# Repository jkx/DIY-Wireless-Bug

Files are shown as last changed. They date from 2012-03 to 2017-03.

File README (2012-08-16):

DIY Wireless Bug
================

bugOne hardware and software git repos. 

You can find more infos here : 
- Introduction => http://dwb.ilhost.fr/doku.php/start
- Hardware => http://dwb.ilhost.fr/doku.php/bugone:hardware

All works here is under CC Attribution-NonCommercial-ShareAlike licence.
Check out this for licence information :
- http://creativecommons.org/licenses/by-nc-sa/3.0/

Brought to you, by MDL29 Electronic Team 
- http://mdl29.net

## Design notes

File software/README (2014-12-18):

Software Guidelines
===================
When you use the bugOne framework to developp apps, please to follow this 
guidelines : 

- LED1 (red one) must be used to represent the power supply. On normal 
  operation it should be ON. If your application need to power consumption,
  you can turn it OFF, but alway turn it ON when the app is running. 

- LED2 (blue one) must be used for radio channel. It should blink on receive
  or transmit. We can imagine two kind of blinking, 1 long for transmition,
  2 short blinks for reception.

- At during boot, both leds should be ON.

- Tabulation, please try to follow the GNU coding style : 4 spaces

- Battery powered bugOne should return the bandgap voltage in the first field

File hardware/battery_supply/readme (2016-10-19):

# Board description

This board is a small battery supply card. It uses a Microchip MCP1640 boost
converter, and is usable with a single 1.5V battery. It is designed to provide a
3.3V (or 5v, depending on the resistor) output on Vcc. 

Please note that this is a very basic board : it does not make use of advanced
features such as Vin to Vout connection and enables. 

# Parts names

U1 : MCP1640
L1 : B82462G4472M (EPCOS), 4.7uH power choke
R1 : 976kOhm, 0805 package
R2 : 562kOhm, 0805 package (for 3.3V)
R2 (alt) : 309kOhm, 0805 package (5V)
C1 : 4.7uF, 1206 package
C2 : 10uF, 1206 package
VIN : 0.7 to 1.7V

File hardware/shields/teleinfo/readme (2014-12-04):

# Board description

This shield is a simple prototype for teleinfo reading. It is based on a simple design, with a single SHF620A optocoupler for demodulation. The LED blinks when data is available on RX.

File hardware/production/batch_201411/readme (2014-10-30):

Production files for November 2014 batch

The aim is to get the following boards : 
	- 70 bugOne_mini
	- 25+ sensor shields
	- 5+ sht21 breakout
	- 35 battery power shields
	- optionnally, 5+ repeater

This has been done in 3 different boards (10x10cm). A .8mm cut line is used, the
cutter can only cut through a whole board, which limits sorting possibilities.

# Boards description

batch1 : 4 bugOne_mini, 2 battery power shields, 2 sht21 breakout
batch2 : 2 bugOne_mini, 2 sensor shields, 2 battery power shields, 1 repeater board
batch3 : same as batch 1

Expected order is 10 batch1, 10 batch2, and 10 batch3. SeeedStudio charges ~22$
10 pieces of 10x10cm printed boards, which amounts to 66$ before taxes and
shipping fees.

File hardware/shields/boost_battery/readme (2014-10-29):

# Board description

This board is a small boost card pin compatible with bugOne Mini. It uses a
Microchip MCP1640 boost converter, and is usable with a single 1.5V battery. It
is designed to provide a 3.3V output on Vcc, and the 1.5V input on Vss if the
jumper is in place (used to check remaining battery with the sensor shield).

# Parts names

U1 : MCP1640
L1 : B82462G4472M (EPCOS), 4.7uH power choke
R1 : 976kOhm, 0805 package
R2 : 562kOhm, 0805 package
C1 : 4.7uF, 1206 package
C2 : 10uF, 1206 package
VIN : 0.7 to 1.7V

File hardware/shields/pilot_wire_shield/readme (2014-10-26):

# Board description

This shield is designed to provide electric heater control through "pilot wire"
interface. It uses 2 MOC to control positive and negative part of the input
sinusoid. It also uses a shift register to store values without need of the AVR.
This shield is designed to go BELOW the bugOne main board. It would otherwise 
hide the antenna and leds.

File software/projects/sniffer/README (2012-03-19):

For your board: use make && make load to flash sniffer.c one your bugOne.

Use python commands to interact with other bugOne cards.

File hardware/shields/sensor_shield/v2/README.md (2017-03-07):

## Board description

This shield is designed to provide different possibilities to create a sensor
shield, for relative humidity, temperature, pressure and lux. All choices do not need to be
soldered. 

## BOM 

The following components can be soldered on the board:
   - TAOS TSL2561 (U1)
   - TE HTU2XD(F) (U2)
   - Maxim DS18B20 (U3): popular 1-Wire temperature sensor Maxim. 
		http://datasheets.maximintegrated.com/en/ds/DS18B20

Other possibilites were:
	- Sensirion SHT31D : cheap (~5$ at Farnell) QFP sensor, using I2C for communication
	https://www.sensirion.com/fileadmin/user_upload/customers/sensirion/Dokumente/Humidity_Sensors/Sensirion_Humidity_Sensors_SHT3x_Datasheet_digital.pdf
	- Bosch BME280 : temperature, humidity and pressure. The package seems more protected than the Sensirion (and we had troubles with the Sensirion which seems to age fast). 
	https://ae-bst.resource.bosch.com/media/_tech/media/datasheets/BST-BME280_DS001-11.pdf
	- Rohm BH1750 : Light sensor (Luxmeter)
	http://rohmfs.rohm.com/en/products/databook/datasheet/ic/sensor/light/bh1750fvi-e.pdf

C1 and C2 stabilizes the power line for their components. Expected value is 100nF. They need to be placed near their components
R1 and R2 are the pull-up resistors for I2C bus. Values can range from 1.8 to 10k. I prefer using 1.8k (strong pull-up), but the higher the resistance, the lower the current consumption. 
R3 is the pull-up for the interrupt line of the TSL2561. Value is 100k (datasheet)
R4 is the pull-up resistor for 1-Wire bus. Expected value is 4.7kOhm.
R5 and R6 are a voltage divider for battery sensing. It divides voltage by 2, allowing a battery up to 6.6V. 
R7 and R8 are only there to provide solder pads. Only one can be soldered at a time. They allow selection of the power line for which the voltage must be measured (Vss or Vcc)

U1, U2 and U3 uses I2C.

Shield pinout : 

CONN1_2 : FOUT, PD5
CONN1-5 : 1-Wire bus, PB1
CONN2_4 : SCL, PC5
CONN2_5 : SDA, PC4
CONN2_6 : battery sense, PC3

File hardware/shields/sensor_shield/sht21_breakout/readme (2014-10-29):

# Board description

Small breakout board for the Sensirion SHT21/SHT25 T/RH sensor. The board is 
compatible with repeater pinout. It also allows a photoresistor on it, for
ambient light sensing.

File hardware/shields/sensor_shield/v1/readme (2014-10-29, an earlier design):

# Board description

This shield is designed to provide different possibilities to create a sensor
shield, for relative humidity and temperature. All choices do not need to be
soldered. A 8P8C (RJ45) modular connector is provided in order to export the sensors
further from the board (to avoid sensor noise). A repeater board is also
provided (in the corresponding subdirectory), in order to connect the sensors
through RJ45 wire.

# BOM

The following components can be soldered on the board:
	- Sensirion SHT21/SHT25 (U1): cheap (~4$) QFP sensor, using I2C for communication
		http://www.sensirion.com/fileadmin/user_upload/customers/sensirion/Dokumente/Humidity/Sensirion_Humidity_SHT21_Datasheet_V4.pdf
		Resolution and precision are interesting, and it is low power (less than 1uA when asleep, 1mA when measuring temp, 330uA when measuring RH). However, it is difficult to solder...
	- HH10D (U2): this is a humidity sensor provided by HopeRF. It is quite expensive but efficient. 
		http://www.hoperf.com/upload/sensor/hh10d.pdf
	- DHT11 (U3): cheap but unprecise RH and temp sensor. It is widely used.
		http://www.exp-tech.de/service/datasheet/DHT11.PDF
	- DS18B20 (U4): popular 1-Wire temperature sensor from Maxim. 
		http://datasheets.maximintegrated.com/en/ds/DS18B20.pdf

2 pull-up resistors can be soldered. 
	R1 is the pull-up resistor for DHT11. Expected value is 5kOhm if the sensor is connected through a wire shorter than 20m. 
	R2 is the pull-up resistor for 1-Wire bus. Expected value is 4.7kOhm.
	R3 and R4 are the pull-up resistors for I2C bus. Values can range from 1.8 to 10k. I prefer using 1.8k (strong pull-up), but the higher the resistance, the lower the current consumption.

# Pinout

RJ45 pinout:

P1: 1-Wire bus, PB1
P2: Vcc
P3: SDA, PC4
P4: SCL, PC5
P5: FOUT pin if HH10D connected (unusable if HH10D on the shield), PD5
P6: DATA1 pin if DHT11 connected (unusable if DHT11 on the shield), PD3
P7: PC2 (ADC pin, usable for light sensor for example)
P8: GND

Shield pinout : 

CONN1_2 : FOUT, PD5
CONN1-5 : 1-Wire bus, PB1
CONN2_3 : DHT11 DATA1, PD3
CONN2_4 : SCL, PC5
CONN2_5 : SDA, PC4
CONN2_6 : battery sense, PC3
CONN2_7 : external connector, PC2

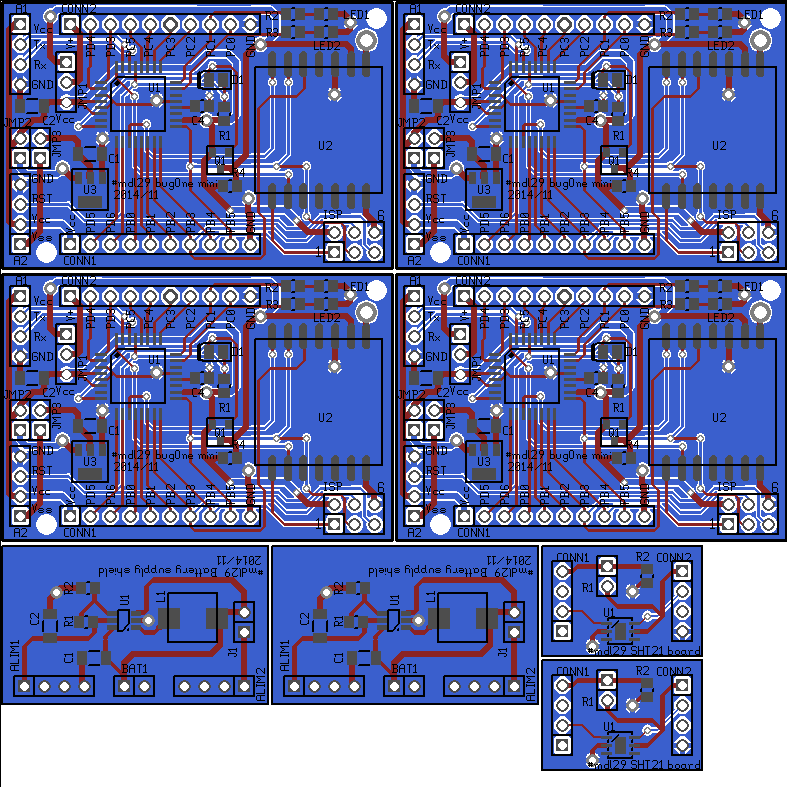
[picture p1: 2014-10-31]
hardware/production/batch_201411/batch1.png

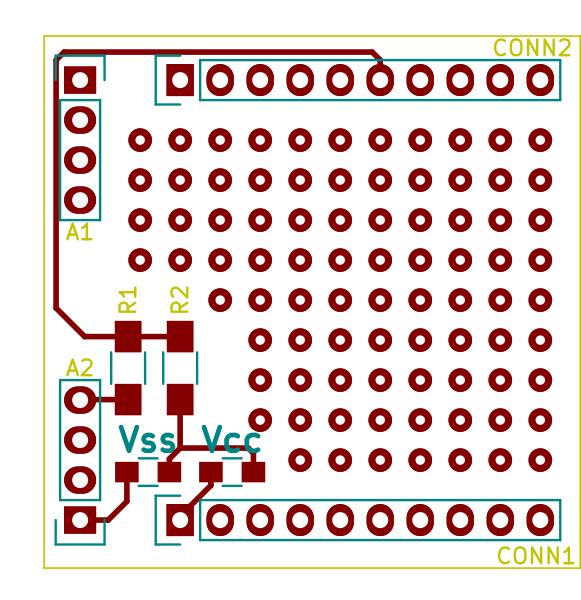
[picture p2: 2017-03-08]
hardware/shields/proto_shield/proto_shield.png

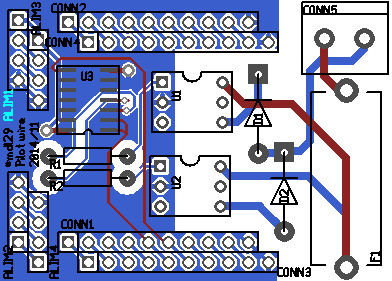
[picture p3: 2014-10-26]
hardware/shields/pilot_wire_shield/pilot_wire.png

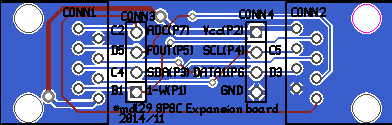
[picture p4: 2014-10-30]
hardware/shields/sensor_shield/repeater/repeater.png

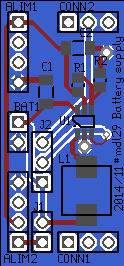
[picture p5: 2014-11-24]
hardware/shields/boost_battery/boost_battery.png

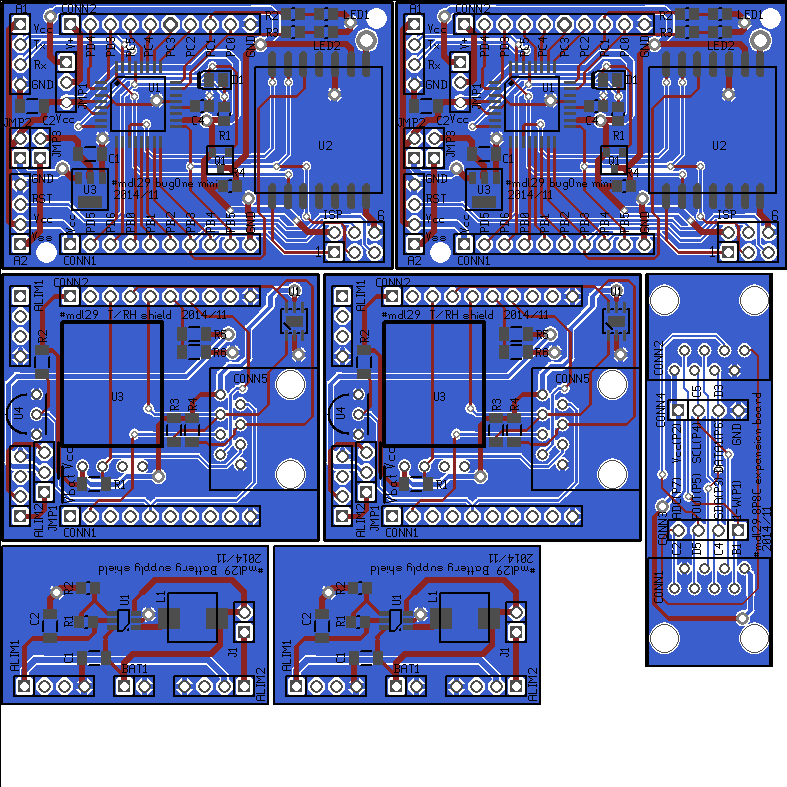
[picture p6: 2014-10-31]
hardware/production/batch_201411/batch2.png

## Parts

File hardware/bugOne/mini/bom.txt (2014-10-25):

Connectors : 
CONN1	: 10 pins female header 
CONN2	: 10 pins female header
ALIM1	: 4 pins female header (can be soldered below to add a bigger power shield)
ALIM2	: 4 pins female header (can be soldered below to add a bigger power shield)
ISP	: 2 rows 3-pins male header

Components : 
U1 	: ATmegaX8 with TQFP-32 package (ATmega168, ATmega328, ATmega8,...)
U2 	: RFM12B from hopeRF (or pin compatible, such as RFM69HW)
U3 	: LDO regulator, Microchip MCP1700 or Torex XC6206, adapts C1 and C2 according to choice. SOT-89 package
Q1		: P-MOSFET, SOT-23 package. Pin example is BSS315P from Infineon (draws 1uA), low cost
R0		: 0 ohm, soldered to replace U3 if no LDO required
R1		: 10k, 0805 package
R2		: 1k, 0805 package
R3		: 1k, 0805 package
R4		: 0 ohm, soldered to replace Q1 if no MOSFET required
C1		: 1206 package, 1u ceramic for XC6206, 
C2		: 1206 package, 1u ceramic for XC6206,
C4		: 100nF, 0805 package
D1		: SOD-323 package, "usual" blocking diod
LED1	: red led
LED2	: blue led

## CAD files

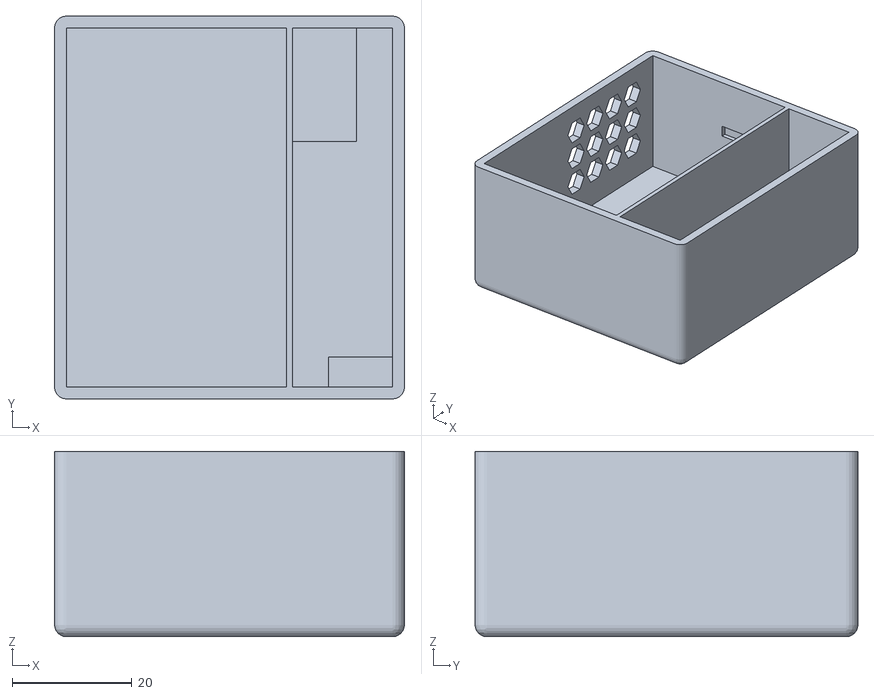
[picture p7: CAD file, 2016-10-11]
hardware/case/bugone_case_vented.stl
58.5 x 64.0 x 31.0

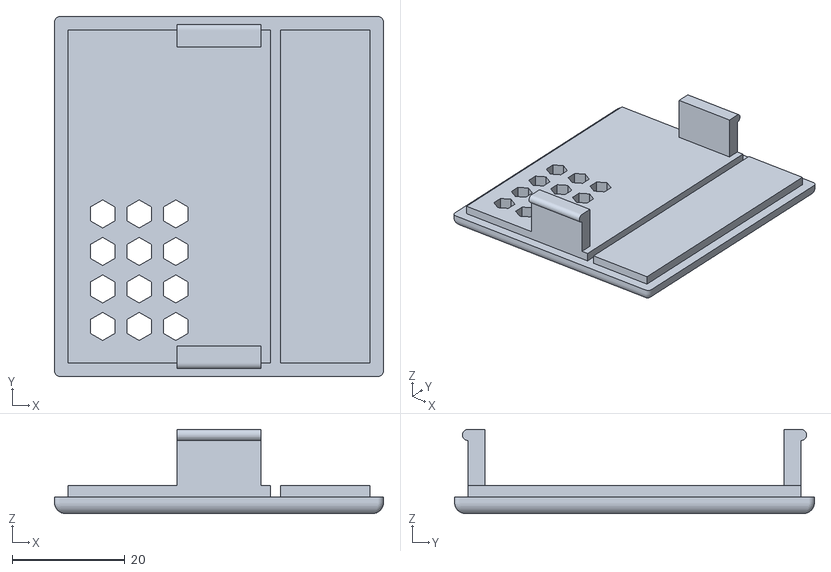
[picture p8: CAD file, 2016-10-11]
hardware/case/bugone_lid_vented.stl
58.5 x 64.0 x 15.0

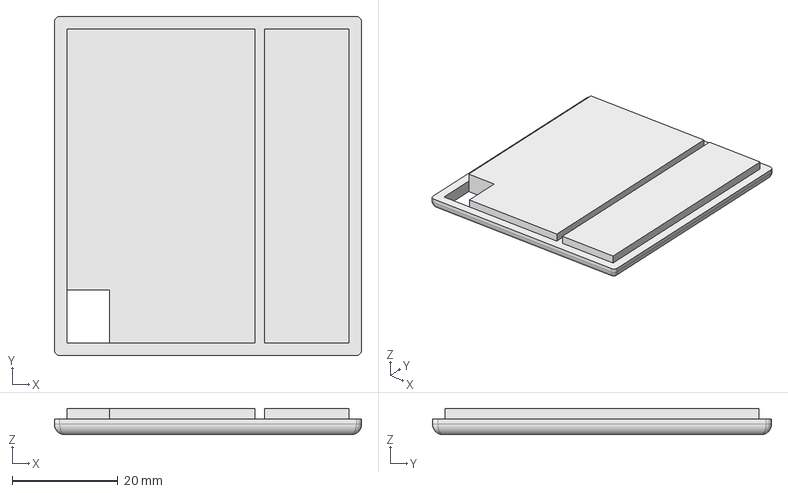
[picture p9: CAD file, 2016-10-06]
hardware/case/bugone_14500_vert_lid.fcstd
58.0 x 64.0 x 5.00 mm

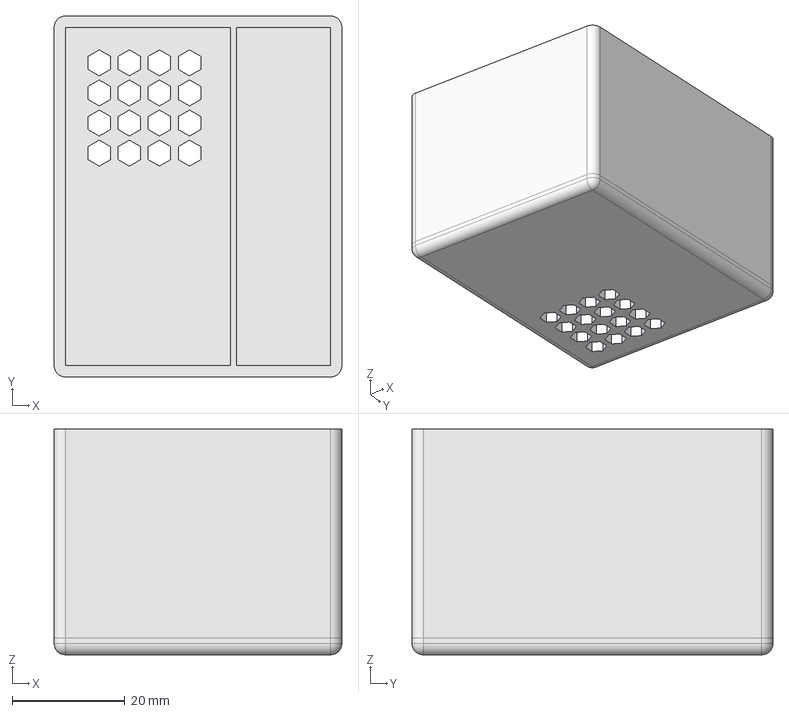
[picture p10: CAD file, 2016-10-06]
hardware/case/bugone_14500_vert_case.fcstd
51.0 x 64.0 x 40.0 mm

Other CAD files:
hardware/case/bugone_14500_lid.fcstd
hardware/case/bugone_14500_case.fcstd

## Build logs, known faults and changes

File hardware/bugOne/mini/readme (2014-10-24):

# Board description

This is a miniaturized version of bugOne board. Power connectors have been
rotated in order to reduce the board length below 50 mm. Shields stay compatible
in size. 

# Noticeable changes

	* A PMOS has been introduced, to provide a shutdown feature on selected
	  devices. RF transmitter can now be completely powered off, by setting pin
	  PB7 as input (a pull up is used), and powerd on by setting it to 0. This
	  controlled power line is accessible as V+ on CONN2.
	* Power connectors have been modified
	* A new LDO regulator is used, either MCP1700 or XC6206 (preferred choice).
	  They aure pin compatible. 
	* Grounded mounting holes are provided. One of them is located near the
	  antenna output, providing an easy way to ground an external antenna.
	* R0 is not used as a fuse anymore, but as a bypass in case no regulator is
	  soldered. The same mechanism is provided by the shield, in order to keep
     the same pinout as before on the shield connectors.
	* ISP connector is now usable even with a shield connected (same line as the
	  antenna)

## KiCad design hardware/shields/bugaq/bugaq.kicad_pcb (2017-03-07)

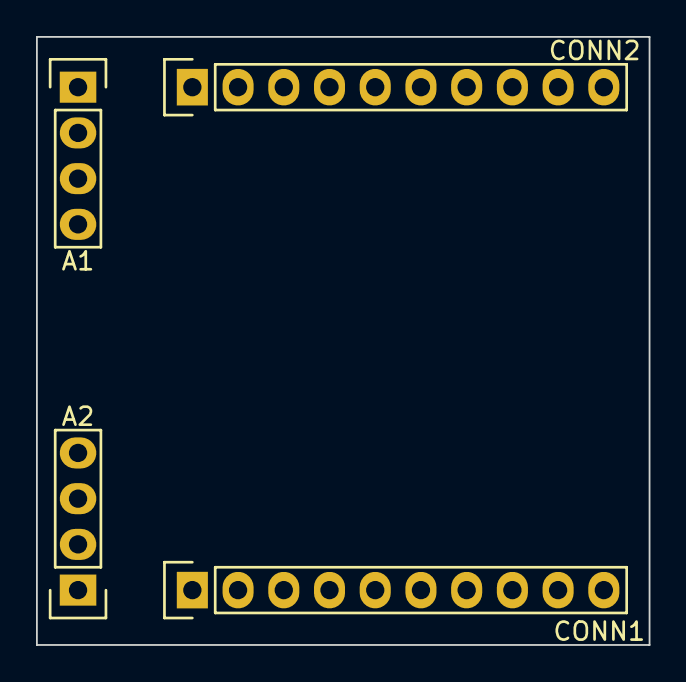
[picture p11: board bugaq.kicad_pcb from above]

Board: 2 copper layers, 34.0 x 33.8 mm, 4 parts (0 on the bottom side), 2 nets, no tracks yet.

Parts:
A1, A2: CONN_01X04; Pin_Header_Straight_1x04
CONN1, CONN2: CONN_01X10; Pin_Header_Straight_1x10

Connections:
GND: A1.4, A2.4, CONN1.10, CONN2.10
VCC: A1.1, A2.2, CONN1.1

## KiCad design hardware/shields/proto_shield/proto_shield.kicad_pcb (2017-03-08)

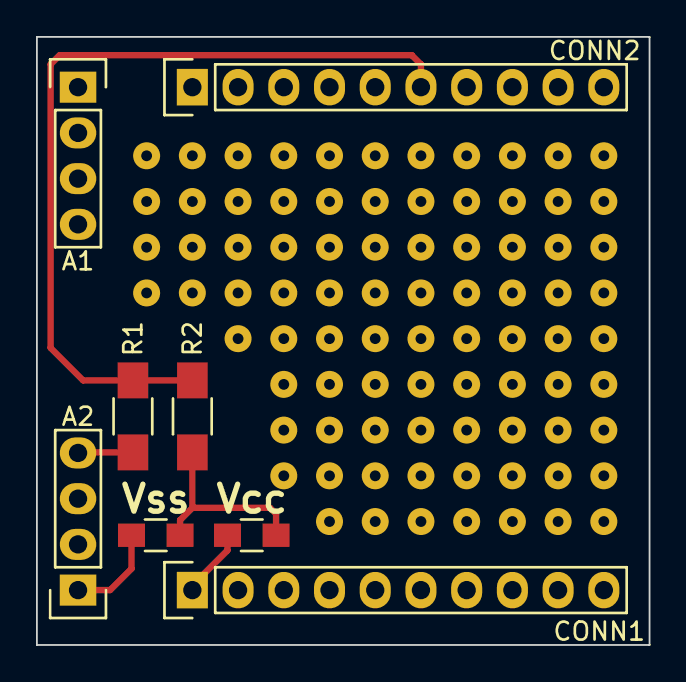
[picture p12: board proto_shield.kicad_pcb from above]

Board: 2 copper layers, 34.0 x 33.8 mm, 8 parts (0 on the bottom side), 5 nets.

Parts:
A1, A2: CONN_01X04; Pin_Header_Straight_1x04
CONN1, CONN2: CONN_01X10; Pin_Header_Straight_1x10
R1, R2: 470k; R_1206_HandSoldering
R7, R8: 0; R_0805_HandSoldering

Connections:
GND: A1.4, A2.4, CONN1.10, CONN2.10, R1.2
unnamed: R2.1, R7.2, R8.2
PC3: CONN2.6, R1.1, R2.2
VCC: A1.1, A2.2, CONN1.1, R7.1
VSS: A2.1, R8.1

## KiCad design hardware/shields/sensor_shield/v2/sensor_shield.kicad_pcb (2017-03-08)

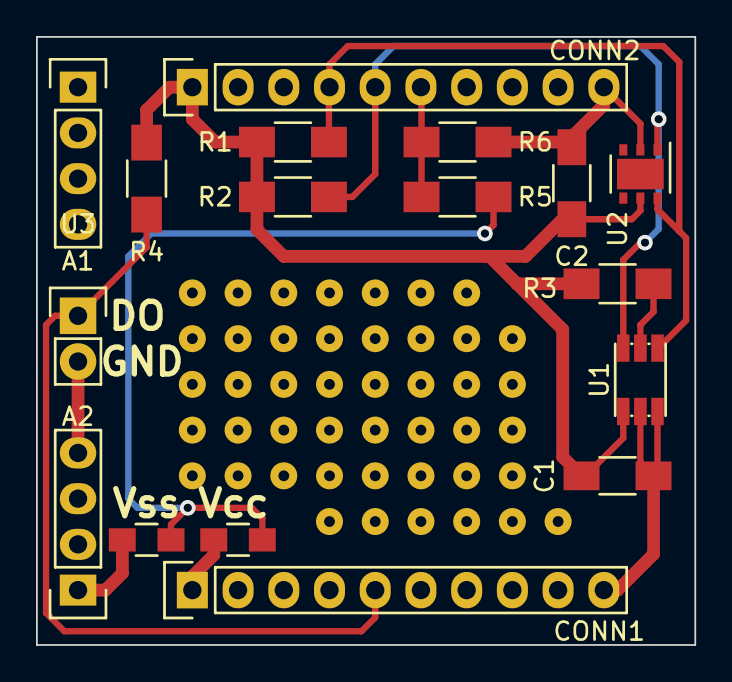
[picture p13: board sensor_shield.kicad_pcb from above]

Board: 2 copper layers, 36.6 x 33.8 mm, 17 parts (0 on the bottom side), 10 nets.

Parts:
A1, A2: CONN_01X04; Pin_Header_Straight_1x04
C1, C2: 100n; C_1206_HandSoldering
CONN1, CONN2: CONN_01X10; Pin_Header_Straight_1x10
R1, R2: 1.8k; R_1206_HandSoldering
R3: 100k; R_1206_HandSoldering
R4: 4.7k; R_1206_HandSoldering
R5, R6: 200k; R_1206_HandSoldering
R7, R8: 0; R_0805_HandSoldering
U1: TSL2561; TMB6
U2: HTU2XD; DFN-6-1EP_3x3mm_Pitch0.95mm
U3: CONN_01X02; Pin_Header_Straight_1x02

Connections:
GND: A1.4, A2.4, C1.2, C2.2, CONN1.10, CONN2.10, R6.2, U1.2, U1.3, U2.2, U3.2
unnamed: R3.2, U1.5
unnamed: R5.1, R7.2, R8.2
PB1: CONN1.5, R4.2, U3.1
PC3: CONN2.6, R5.2, R6.1
SCL: CONN2.4, R1.2, U1.4, U2.6
SDA: CONN2.5, R2.2, U1.6, U2.1
VCC: A1.1, A2.2, CONN1.1, R8.1
VEE: C1.1, C2.1, CONN2.1, R1.1, R2.1, R3.1, R4.1, U1.1, U2.5
VSS: A2.1, R7.1

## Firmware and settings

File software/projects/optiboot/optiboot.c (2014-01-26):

/**********************************************************/
/* Optiboot bootloader for Arduino                        */
/*                                                        */
/* http://optiboot.googlecode.com                         */
/*                                                        */
/* Arduino-maintained version : See README.TXT            */
/* http://code.google.com/p/arduino/                      */
/*  It is the intent that changes not relevant to the     */
/*  Arduino production envionment get moved from the      */
/*  optiboot project to the arduino project in "lumps."   */
/*                                                        */
/* Heavily optimised bootloader that is faster and        */
/* smaller than the Arduino standard bootloader           */
/*                                                        */
/* Enhancements:                                          */
/*   Fits in 512 bytes, saving 1.5K of code space         */
/*   Background page erasing speeds up programming        */
/*   Higher baud rate speeds up programming               */
/*   Written almost entirely in C                         */
/*   Customisable timeout with accurate timeconstant      */
/*   Optional virtual UART. No hardware UART required.    */
/*   Optional virtual boot partition for devices without. */
/*                                                        */
/* What you lose:                                         */
/*   Implements a skeleton STK500 protocol which is       */
/*     missing several features including EEPROM          */
/*     programming and non-page-aligned writes            */
/*   High baud rate breaks compatibility with standard    */
/*     Arduino flash settings                             */
/*                                                        */
/* Fully supported:                                       */
/*   ATmega168 based devices  (Diecimila etc)             */
/*   ATmega328P based devices (Duemilanove etc)           */
/*                                                        */
/* Beta test (believed working.)                          */
/*   ATmega8 based devices (Arduino legacy)               */
/*   ATmega328 non-picopower devices                      */
/*   ATmega644P based devices (Sanguino)                  */
/*   ATmega1284P based devices                            */
/*   ATmega1280 based devices (Arduino Mega)              */
/*                                                        */
/* Alpha test                                             */
/*   ATmega32                                             */
/*                                                        */
/* Work in progress:                                      */
/*   ATtiny84 based devices (Luminet)                     */
/*                                                        */
/* Does not support:                                      */
/*   USB based devices (eg. Teensy, Leonardo)             */
/*                                                        */
/* Assumptions:                                           */
/*   The code makes several assumptions that reduce the   */
/*   code size. They are all true after a hardware reset, */
/*   but may not be true if the bootloader is called by   */
/*   other means or on other hardware.                    */
/*     No interrupts can occur                            */
/*     UART and Timer 1 are set to their reset state      */
/*     SP points to RAMEND                                */
/*                                                        */
/* Code builds on code, libraries and optimisations from: */
/*   stk500boot.c          by Jason P. Kyle               */
/*   Arduino bootloader    http://arduino.cc              */
/*   Spiff's 1K bootloader http://spiffie.org/know/arduino_1k_bootloader/bootloader.shtml */
/*   avr-libc project      http://nongnu.org/avr-libc     */
/*   Adaboot               http://www.ladyada.net/library/arduino/bootloader.html */
/*   AVR305                Atmel Application Note         */
/*                                                        */
/* This program is free software; you can redistribute it */
/* and/or modify it under the terms of the GNU General    */
/* Public License as published by the Free Software       */
/* Foundation; either version 2 of the License, or        */
/* (at your option) any later version.                    */
/*                                                        */
/* This program is distributed in the hope that it will   */
/* be useful, but WITHOUT ANY WARRANTY; without even the  */
/* implied warranty of MERCHANTABILITY or FITNESS FOR A   */
/* PARTICULAR PURPOSE.  See the GNU General Public        */
/* License for more details.                              */
/*                                                        */
/* You should have received a copy of the GNU General     */
/* Public License along with this program; if not, write  */
/* to the Free Software Foundation, Inc.,                 */
/* 59 Temple Place, Suite 330, Boston, MA  02111-1307 USA */
/*                                                        */
/* Licence can be viewed at                               */
/* http://www.fsf.org/licenses/gpl.txt                    */
/*                                                        */
/**********************************************************/


/**********************************************************/
/*                                                        */
/* Optional defines:                                      */
/*                                                        */
/**********************************************************/
/*                                                        */
/* BIG_BOOT:                                              */
/* Build a 1k bootloader, not 512 bytes. This turns on    */
/* extra functionality.                                   */
/*                                                        */
/* BAUD_RATE:                                             */
/* Set bootloader baud rate.                              */
/*                                                        */
/* LUDICROUS_SPEED:                                       */
/* 230400 baud :-)                                        */
/*                                                        */
/* SOFT_UART:                                             */
/* Use AVR305 soft-UART instead of hardware UART.         */
/*                                                        */
/* LED_START_FLASHES:                                     */
/* Number of LED flashes on bootup.                       */
/*                                                        */
/* LED_DATA_FLASH:                                        */
/* Flash LED when transferring data. For boards without   */
/* TX or RX LEDs, or for people who like blinky lights.   */
/*                                                        */
/* SUPPORT_EEPROM:                                        */
/* Support reading and writing from EEPROM. This is not   */
/* used by Arduino, so off by default.                    */
/*                                                        */
/* TIMEOUT_MS:                                            */
/* Bootloader timeout period, in milliseconds.            */
/* 500,1000,2000,4000,8000 supported.                     */
/*                                                        */
/* UART:                                                  */
/* UART number (0..n) for devices with more than          */
/* one hardware uart (644P, 1284P, etc)                   */
/*                                                        */
/**********************************************************/


/**********************************************************/
/* Version Numbers!                                       */
/*                                                        */
/* Arduino Optiboot now includes this Version number in   */
/* the source and object code.                            */
/*                                                        */
/* Version 3 was released as zip from the optiboot        */
/*  repository and was distributed with Arduino 0022.     */
/* Version 4 starts with the arduino repository commit    */
/*  that brought the arduino repository up-to-date with   */
/*  the optiboot source tree changes since v3.            */
/* Version 5 was created at the time of the new Makefile  */
/*  structure (Mar, 2013), even though no binaries changed*/
/* It would be good if versions implemented outside the   */
/*  official repository used an out-of-seqeunce version   */
/*  number (like 104.6 if based on based on 4.5) to       */
/*  prevent collisions.                                   */
/*                                                        */
/**********************************************************/

/**********************************************************/
/* Edit History:					  */
/*							  */
/* Mar 2013                                               */
/* 5.0 WestfW: Major Makefile restructuring.              */
/*             See Makefile and pin_defs.h                */
/*             (no binary changes)                        */
/*                                                        */
/* 4.6 WestfW/Pito: Add ATmega32 support                  */
/* 4.6 WestfW/radoni: Don't set LED_PIN as an output if   */
/*                    not used. (LED_START_FLASHES = 0)   */
/* Jan 2013						  */
/* 4.6 WestfW/dkinzer: use autoincrement lpm for read     */
/* 4.6 WestfW/dkinzer: pass reset cause to app in R2      */
/* Mar 2012                                               */
/* 4.5 WestfW: add infrastructure for non-zero UARTS.     */
/* 4.5 WestfW: fix SIGNATURE_2 for m644 (bad in avr-libc) */
/* Jan 2012:                                              */
/* 4.5 WestfW: fix NRWW value for m1284.                  */
/* 4.4 WestfW: use attribute OS_main instead of naked for */
/*             main().  This allows optimizations that we */
/*             count on, which are prohibited in naked    */
/*             functions due to PR42240.  (keeps us less  */
/*             than 512 bytes when compiler is gcc4.5     */
/*             (code from 4.3.2 remains the same.)        */
/* 4.4 WestfW and Maniacbug:  Add m1284 support.  This    */
/*             does not change the 328 binary, so the     */
/*             version number didn't change either. (?)   */
/* June 2011:                                             */
/* 4.4 WestfW: remove automatic soft_uart detect (didn't  */
/*             know what it was doing or why.)  Added a   */
/*             check of the calculated BRG value instead. */
/*             Version stays 4.4; existing binaries are   */
/*             not changed.                               */
/* 4.4 WestfW: add initialization of address to keep      */
/*             the compiler happy.  Change SC'ed targets. */
/*             Return the SW version via READ PARAM       */
/* 4.3 WestfW: catch framing errors in getch(), so that   */
/*             AVRISP works without HW kludges.           */
/*  http://code.google.com/p/arduino/issues/detail?id=368n*/
/* 4.2 WestfW: reduce code size, fix timeouts, change     */
/*             verifySpace to use WDT instead of appstart */
/* 4.1 WestfW: put version number in binary.		  */
/**********************************************************/

#define OPTIBOOT_MAJVER 5
#define OPTIBOOT_MINVER 0

#define MAKESTR(a) #a
#define MAKEVER(a, b) MAKESTR(a*256+b)

asm("  .section .version\n"
    "optiboot_version:  .word " MAKEVER(OPTIBOOT_MAJVER, OPTIBOOT_MINVER) "\n"
    "  .section .text\n");


#include <inttypes.h>
#include <avr/io.h>
#include <avr/pgmspace.h>

// <avr/boot.h> uses sts instructions, but this version uses out instructions
// This saves cycles and program memory.
#include "boot.h"


// We don't use <avr/wdt.h> as those routines have interrupt overhead we don't need.

#include "pin_defs.h"
#include "stk500.h"

#ifndef LED_START_FLASHES
#define LED_START_FLASHES 0
#endif

#ifdef LUDICROUS_SPEED
#define BAUD_RATE 230400L
#endif

/* set the UART baud rate defaults */
#ifndef BAUD_RATE
#if F_CPU >= 8000000L
#define BAUD_RATE   115200L // Highest rate Avrdude win32 will support
#elsif F_CPU >= 1000000L
#define BAUD_RATE   9600L   // 19200 also supported, but with significant error
#elsif F_CPU >= 128000L
#define BAUD_RATE   4800L   // Good for 128kHz internal RC
#else
#define BAUD_RATE 1200L     // Good even at 32768Hz
#endif
#endif

#ifndef UART
#define UART 0
#endif

#define BAUD_SETTING (( (F_CPU + BAUD_RATE * 4L) / ((BAUD_RATE * 8L))) - 1 )
#define BAUD_ACTUAL (F_CPU/(8 * ((BAUD_SETTING)+1)))
#define BAUD_ERROR (( 100*(BAUD_RATE - BAUD_ACTUAL) ) / BAUD_RATE)

#if BAUD_ERROR >= 5
#error BAUD_RATE error greater than 5%
#elif BAUD_ERROR <= -5
#error BAUD_RATE error greater than -5%
#elif BAUD_ERROR >= 2
#warning BAUD_RATE error greater than 2%
#elif BAUD_ERROR <= -2
#warning BAUD_RATE error greater than -2%
#endif

#if 0
/* Switch in soft UART for hard baud rates */
/*
 * I don't understand what this was supposed to accomplish, where the
 * constant "280" came from, or why automatically (and perhaps unexpectedly)
 * switching to a soft uart is a good thing, so I'm undoing this in favor
 * of a range check using the same calc used to config the BRG...
 */
#if (F_CPU/BAUD_RATE) > 280 // > 57600 for 16MHz
#ifndef SOFT_UART
#define SOFT_UART
#endif
#endif
#else // 0
#if (F_CPU + BAUD_RATE * 4L) / (BAUD_RATE * 8L) - 1 > 250
#error Unachievable baud rate (too slow) BAUD_RATE 
#endif // baud rate slow check
#if (F_CPU + BAUD_RATE * 4L) / (BAUD_RATE * 8L) - 1 < 3
#error Unachievable baud rate (too fast) BAUD_RATE 
#endif // baud rate fastn check
#endif
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
int main(void) {
  uint8_t ch;

  /*
   * Making these local and in registers prevents the need for initializing
   * them, and also saves space because code no longer stores to memory.
   * (initializing address keeps the compiler happy, but isn't really
   *  necessary, and uses 4 bytes of flash.)
   */
  register uint16_t address = 0;
  register uint8_t  length;

  // After the zero init loop, this is the first code to run.
  //
  // This code makes the following assumptions:
  //  No interrupts will execute
  //  SP points to RAMEND
  //  r1 contains zero
  //
  // If not, uncomment the following instructions:
  // cli();
  asm volatile ("clr __zero_reg__");
#if defined(__AVR_ATmega8__) || defined (__AVR_ATmega32__)
  SP=RAMEND;  // This is done by hardware reset
#endif

  // Adaboot no-wait mod
  ch = MCUSR;
  MCUSR = 0;
  if (!(ch & _BV(EXTRF))) appStart(ch);

#if LED_START_FLASHES > 0
  // Set up Timer 1 for timeout counter
  TCCR1B = _BV(CS12) | _BV(CS10); // div 1024
#endif
#ifndef SOFT_UART
#if defined(__AVR_ATmega8__) || defined (__AVR_ATmega32__)
  UCSRA = _BV(U2X); //Double speed mode USART
  UCSRB = _BV(RXEN) | _BV(TXEN);  // enable Rx & Tx
  UCSRC = _BV(URSEL) | _BV(UCSZ1) | _BV(UCSZ0);  // config USART; 8N1
  UBRRL = (uint8_t)( (F_CPU + BAUD_RATE * 4L) / (BAUD_RATE * 8L) - 1 );
#else
  UART_SRA = _BV(U2X0); //Double speed mode USART0
  UART_SRB = _BV(RXEN0) | _BV(TXEN0);
  UART_SRC = _BV(UCSZ00) | _BV(UCSZ01);
  UART_SRL = (uint8_t)( (F_CPU + BAUD_RATE * 4L) / (BAUD_RATE * 8L) - 1 );
#endif
#endif

  // Set up watchdog to trigger after 500ms
  watchdogConfig(WATCHDOG_8S);

#if (LED_START_FLASHES > 0) || defined(LED_DATA_FLASH)
  /* Set LED pin as output */
  LED_DDR |= _BV(LED);
#endif

#ifdef SOFT_UART
  /* Set TX pin as output */
  UART_DDR |= _BV(UART_TX_BIT);
#endif

#if LED_START_FLASHES > 0
  /* Flash onboard LED to signal entering of bootloader */
  flash_led(LED_START_FLASHES * 2);
#endif

  /* Forever loop */
  for (;;) {
    /* get character from UART */
    ch = getch();

    if(ch == STK_GET_PARAMETER) {
      unsigned char which = getch();
      verifySpace();
      if (which == 0x82) {
	/*
	 * Send optiboot version as "minor SW version"
	 */
	putch(OPTIBOOT_MINVER);
      } else if (which == 0x81) {
	  putch(OPTIBOOT_MAJVER);
      } else {
	/*
	 * GET PARAMETER returns a generic 0x03 reply for
         * other parameters - enough to keep Avrdude happy
	 */
	putch(0x03);
      }
    }
    else if(ch == STK_SET_DEVICE) {
      // SET DEVICE is ignored
      getNch(20);
    }
    else if(ch == STK_SET_DEVICE_EXT) {
      // SET DEVICE EXT is ignored
      getNch(5);
    }
    else if(ch == STK_LOAD_ADDRESS) {
      // LOAD ADDRESS
      uint16_t newAddress;
      newAddress = getch();
      newAddress = (newAddress & 0xff) | (getch() << 8);
#ifdef RAMPZ
      // Transfer top bit to RAMPZ
      RAMPZ = (newAddress & 0x8000) ? 1 : 0;
#endif
      newAddress += newAddress; // Convert from word address to byte address
      address = newAddress;
      verifySpace();
    }
    else if(ch == STK_UNIVERSAL) {
      // UNIVERSAL command is ignored
      getNch(4);
      putch(0x00);
    }
    /* Write memory, length is big endian and is in bytes */
    else if(ch == STK_PROG_PAGE) {
      // PROGRAM PAGE - we support flash programming only, not EEPROM
      uint8_t *bufPtr;
      uint16_t addrPtr;

      getch();			/* getlen() */
      length = getch();
      getch();

      // If we are in RWW section, immediately start page erase
      if (address < NRWWSTART) __boot_page_erase_short((uint16_t)(void*)address);

      // While that is going on, read in page contents
      bufPtr = buff;
      do *bufPtr++ = getch();
      while (--length);

      // If we are in NRWW section, page erase has to be delayed until now.
      // Todo: Take RAMPZ into account (not doing so just means that we will
      //  treat the top of both "pages" of flash as NRWW, for a slight speed
      //  decrease, so fixing this is not urgent.)
      if (address >= NRWWSTART) __boot_page_erase_short((uint16_t)(void*)address);

      // Read command terminator, start reply
      verifySpace();

      // If only a partial page is to be programmed, the erase might not be complete.
      // So check that here
      boot_spm_busy_wait();

#ifdef VIRTUAL_BOOT_PARTITION
      if ((uint16_t)(void*)address == 0) {
        // This is the reset vector page. We need to live-patch the code so the
        // bootloader runs.
        //
        // Move RESET vector to WDT vector
        uint16_t vect = buff[0] | (buff[1]<<8);
        rstVect = vect;
        wdtVect = buff[8] | (buff[9]<<8);
        vect -= 4; // Instruction is a relative jump (rjmp), so recalculate.
        buff[8] = vect & 0xff;
        buff[9] = vect >> 8;

        // Add jump to bootloader at RESET vector
        buff[0] = 0x7f;
        buff[1] = 0xce; // rjmp 0x1d00 instruction
      }
#endif

      // Copy buffer into programming buffer
      bufPtr = buff;
      addrPtr = (uint16_t)(void*)address;
      ch = SPM_PAGESIZE / 2;
      do {
        uint16_t a;
        a = *bufPtr++;
        a |= (*bufPtr++) << 8;
        __boot_page_fill_short((uint16_t)(void*)addrPtr,a);
        addrPtr += 2;
      } while (--ch);

      // Write from programming buffer
      __boot_page_write_short((uint16_t)(void*)address);
      boot_spm_busy_wait();

#if defined(RWWSRE)
      // Reenable read access to flash
      boot_rww_enable();
#endif

    }
    /* Read memory block mode, length is big endian.  */
    else if(ch == STK_READ_PAGE) {
      // READ PAGE - we only read flash
      getch();			/* getlen() */
      length = getch();
      getch();

      verifySpace();
      do {
#ifdef VIRTUAL_BOOT_PARTITION
        // Undo vector patch in bottom page so verify passes
        if (address == 0)       ch=rstVect & 0xff;
        else if (address == 1)  ch=rstVect >> 8;
        else if (address == 8)  ch=wdtVect & 0xff;
        else if (address == 9) ch=wdtVect >> 8;
        else ch = pgm_read_byte_near(address);
        address++;
#elif defined(RAMPZ)
        // Since RAMPZ should already be set, we need to use EPLM directly.
        // Also, we can use the autoincrement version of lpm to update "address"
        //      do putch(pgm_read_byte_near(address++));
        //      while (--length);
        // read a Flash and increment the address (may increment RAMPZ)
        __asm__ ("elpm %0,Z+\n" : "=r" (ch), "=z" (address): "1" (address));
#else
        // read a Flash byte and increment the address
        __asm__ ("lpm %0,Z+\n" : "=r" (ch), "=z" (address): "1" (address));
#endif
        putch(ch);
      } while (--length);
    }

    /* Get device signature bytes  */
    else if(ch == STK_READ_SIGN) {
      // READ SIGN - return what Avrdude wants to hear
      verifySpace();
      putch(SIGNATURE_0);
      putch(SIGNATURE_1);
      putch(SIGNATURE_2);
    }
    else if (ch == STK_LEAVE_PROGMODE) { /* 'Q' */
      // Adaboot no-wait mod
      watchdogConfig(WATCHDOG_16MS);
      verifySpace();
    }
    else {
      // This covers the response to commands like STK_ENTER_PROGMODE
      verifySpace();
    }
    putch(STK_OK);
  }
}

void putch(char ch) {
#ifndef SOFT_UART
  while (!(UART_SRA & _BV(UDRE0)));
  UART_UDR = ch;
#else
  __asm__ __volatile__ (
    "   com %[ch]\n" // ones complement, carry set
    "   sec\n"
    "1: brcc 2f\n"
    "   cbi %[uartPort],%[uartBit]\n"
    "   rjmp 3f\n"
    "2: sbi %[uartPort],%[uartBit]\n"
    "   nop\n"
    "3: rcall uartDelay\n"
    "   rcall uartDelay\n"
    "   lsr %[ch]\n"
    "   dec %[bitcnt]\n"
    "   brne 1b\n"
    :
    :
      [bitcnt] "d" (10),
      [ch] "r" (ch),
      [uartPort] "I" (_SFR_IO_ADDR(UART_PORT)),
      [uartBit] "I" (UART_TX_BIT)
    :
      "r25"
  );
#endif
}

uint8_t getch(void) {
  uint8_t ch;

#ifdef LED_DATA_FLASH
#if defined(__AVR_ATmega8__) || defined (__AVR_ATmega32__)
  LED_PORT ^= _BV(LED);
#else
  LED_PIN |= _BV(LED);
#endif
#endif
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

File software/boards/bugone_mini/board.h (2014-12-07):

#ifndef BOARD_H
#define BOARD_H

/* CPU frequency */
#define F_CPU 8000000

/* Pinout of leds */
#define LED1 C,1
#define LED2 C,0

/* UART baud rate. Use the speed with the lowest error rate */
#define UART_BAUD_RATE 38400

//Pin that the RFM12's slave select is connected to
#define DDR_SS DDRD
#define PORT_SS PORTD
#define BIT_SS 7

//SPI port
#define DDR_SPI DDRB
#define PORT_SPI PORTB
#define PIN_SPI PINB
#define BIT_MOSI 3
#define BIT_MISO 4
#define BIT_SCK  5
#define BIT_SPI_SS 2
//this is the hardware SS pin of the AVR - it 
//needs to be set to output for the spi-interface to work 
//correctly, independently of the CS pin used for the RFM12

#define MOSFET_PWR_PIN B,7
#define DDR_MOSFET_PWR DDRB
#define PORT_MOSFET_PWR PORTB
#define BIT_MOSFET_PWR 7

#endif

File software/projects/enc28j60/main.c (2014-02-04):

/* 

   A bugnet to ethernet bridge. Forward all bugnet traffic to the
   designated receiver.

   eeprom layout :
    0    : bugone node address (unused)
    1-6  : Mac address
    7-8  : UDP destination port
    9-73 : IP or hostname of receiver

- Documentation
- use mac as bugnet id


*/


#include "bugOne.h"

#include <avr/io.h>
#include <avr/interrupt.h>
#include <util/delay.h>
#include <string.h>

#include <avr/wdt.h>

#include "avr_compat.h"
#include "uart.h"
#include "config.h"

#include "enc28j60.h"
#include "ip_arp_udp_tcp.h"
#include "net.h"

#include "rfm12.h"

// Mac address is BUGONE
//static uint8_t bugone_mac[6] = { 0x42, 0x55, 0x47, 0x4F, 0x4E, 0x45 };

static uint8_t otherside_www_ip[4];	// dns will fill this
// My own IP (DHCP will provide a value for it):
static uint8_t myip[4] = { 0, 0, 0, 0 };

// Default gateway (DHCP will provide a value for it):
static uint8_t gwip[4] = { 0, 0, 0, 0 };

#define TRANS_NUM_GWMAC 1
static uint8_t gwmac[6];
#define TRANS_NUM_WEBMAC 2
static uint8_t otherside_www_gwmac[6];
// Netmask (DHCP will provide a value for it):
static uint8_t netmask[4];

extern uint8_t dnsip[4];

static int8_t processing_state = 0;
static uint8_t start_udp_client = 0;
extern uint8_t seconds;
#define MYUDPPORT 3000

#define BUFFER_SIZE 350
static uint8_t buf[BUFFER_SIZE + 1];

application_t applications[] = {
    {NULL, NULL, NULL, NULL}
};

// the __attribute__((unused)) is a gcc compiler directive to avoid warnings about unsed variables.
void
arpresolver_result_callback(uint8_t * ip
			    __attribute__ ((unused)),
			    uint8_t reference_number, uint8_t * mac)
{
    uint8_t i = 0;
    if (reference_number == TRANS_NUM_GWMAC) {
	// copy mac address over:
	while (i < 6) {
	    gwmac[i] = mac[i];
	    i++;
	}
    }
    if (reference_number == TRANS_NUM_WEBMAC) {
	// copy mac address over:
	while (i < 6) {
	    otherside_www_gwmac[i] = mac[i];
	    i++;
	}
    }
}

void print_ip(uint8_t * ip)
{
    char buf[4];
    itoa(*ip++, buf, 10);
    uart_putstr(buf);
    uart_putc('.');
    itoa(*ip++, buf, 10);
    uart_putstr(buf);
    uart_putc('.');
    itoa(*ip++, buf, 10);
    uart_putstr(buf);
    uart_putc('.');
    itoa(*ip++, buf, 10);
    uart_putstr(buf);
}

int main(void)
{
    uint8_t rev;
    uint16_t plen;
    uint16_t i = 0;
    uint16_t dat_p;

    wdt_disable();

    drive(LED1);
    drive(LED2);

    set_output(LED1);
    set_output(LED2);

    uart_init();
    bugone_init(applications);
    wdt_disable();

    enc28j60Init(config.mac);

    uart_putstr_P(PSTR("AVR init complete\r\n"));

    uart_putstr_P(PSTR("enc28j60 rev. "));
    rev = enc28j60getrev();
    itoa(rev, buf, 10);
    uart_putstr(buf);
    uart_putstr_P(PSTR("\r\n"));

    uart_putstr(config.collector);

    uint8_t rval;

    // DHCP handling. Get the initial IP
    rval = 0;
    init_mac(config.mac);
    while (rval == 0) {
	plen = enc28j60PacketReceive(BUFFER_SIZE, buf);
	buf[BUFFER_SIZE] = '\0';
	rval =
	    packetloop_dhcp_initial_ip_assignment(buf, plen,
						  config.mac[5]);
    }
    // we have an IP:
    dhcp_get_my_ip(myip, netmask, gwip);
    client_ifconfig(myip, netmask);
    uart_putstr_P(PSTR("my IP is: "));
    print_ip(myip);
    uart_putstr_P(PSTR("gateway IP is: "));
    print_ip(gwip);
    uart_putstr_P(PSTR("DNS IP is: "));
    print_ip(dnsip);

    // we have a gateway.
    // find the mac address of the gateway (e.g your dsl router).
#define TRANS_NUM_GWMAC 1
    get_mac_with_arp(gwip, TRANS_NUM_GWMAC, &arpresolver_result_callback);
    while (get_mac_with_arp_wait()) {
	// to process the ARP reply we must call the packetloop
	plen = enc28j60PacketReceive(BUFFER_SIZE, buf);
	packetloop_arp_icmp_tcp(buf, plen);
    }

    while (1) {
	uint8_t *bufcontents;
	uint8_t i;

	i++;

	// RFM12 managment
	rfm12_poll();
	if (i > 100) {
	    rfm12_tick();
	    i = 0;
	}

	if (rfm12_rx_status() == STATUS_COMPLETE) {
	    bufcontents = rfm12_rx_buffer();
	    //recv(bufcontents);
	    toggle_output(LED1);
	    if (start_udp_client == 1) {
                uint8_t j;
		uart_putstr_P(PSTR("send UDP packet\r\n"));
                send_udp_prepare(buf, 2000, otherside_www_ip, config.udp_dstport, gwmac);
                // Put the mac address as a bugnet id
                for(j=0; j < 6; j++) {
                    buf[UDP_DATA_P+j]=config.mac[j];
                }
                for(j=0; j < BUGONE_PACKET_SIZE; j++) {
                    buf[UDP_DATA_P+6+j]=bufcontents[j];
                }
                send_udp_transmit(buf,BUGONE_PACKET_SIZE+sizeof(config.mac));
	    }
            rfm12_rx_clear();
	}

	// get the next new packet:
	plen = enc28j60PacketReceive(BUFFER_SIZE, buf);
	buf[BUFFER_SIZE] = '\0';
	// DHCP renew IP:
	plen = packetloop_dhcp_renewhandler(buf, plen);	// for this to work you have to call dhcp_6sec_tick() every 6 sec
	dat_p = packetloop_arp_icmp_tcp(buf, plen);
	if (plen == 0) {
	    // we are idle here
	    if (processing_state == 0) {
		if (!enc28j60linkup())
		    continue;	// only for dnslkup_request we have to check if the link is up. 
		seconds = 0;
		processing_state = 1;
		dnslkup_request(buf, config.collector, gwmac);
		continue;
	    }
	    if (processing_state == 1 && dnslkup_haveanswer()) {
		dnslkup_get_ip(otherside_www_ip);
		uart_putstr_P(PSTR("server IP is: "));
		print_ip(otherside_www_ip);
		processing_state = 2;
	    }
	    if (processing_state == 2) {
		if (route_via_gw(otherside_www_ip)) {
		    // otherside_www_ip is behind the GW
		    i = 0;
		    while (i < 6) {
			otherside_www_gwmac[i] = gwmac[i];
			i++;
		    }
		    processing_state = 4;
		} else {
		    // the web server we want to contact is on the local lan. find the mac:

		    get_mac_with_arp(otherside_www_ip, TRANS_NUM_WEBMAC,
				     &arpresolver_result_callback);
		    processing_state = 3;
		}
		continue;
	    }
	    if (processing_state == 3 && get_mac_with_arp_wait() == 0) {
		// we have otherside_www_gwmac
		processing_state = 4;
	    }
	    if (processing_state == 4) {
		processing_state = 5;
		// we are ready to upload the first measurement data after startup:
		if (start_udp_client == 0)
		    start_udp_client = 1;

	    }
	    if (processing_state == 1) {
		// retry every 20 sec if dns-lookup failed:
		if (seconds > 20) {
		    processing_state = 0;
		}
		// don't try to use web client before
		// we have a result of dns-lookup
		continue;
	    }
	    //----------
	}


	if (dat_p == 0) {	// plen!=0
	    // check for incomming messages not processed
	    // as part of packetloop_arp_icmp_tcp, e.g udp messages
	    udp_client_check_for_dns_answer(buf, plen);
	    continue;
	}

	if (seconds > 6) {
	    dhcp_6sec_tick();
	    seconds = 0;
	}
    }
}

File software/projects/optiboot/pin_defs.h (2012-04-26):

#if defined(__AVR_ATmega168__) || defined(__AVR_ATmega328P__) || defined(__AVR_ATmega88) || defined(__AVR_ATmega8__) || defined(__AVR_ATmega88__)
/* Onboard LED is connected to pin PB5 in Arduino NG, Diecimila, and Duemilanove */ 
#define LED_DDR     DDRC
#define LED_PORT    PORTC
#define LED_PIN     PINC
#define LED         PINC0

#endif

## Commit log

2011-02-20 First steps ..
    [bugOne.sch]
2011-02-27 Added RFM12S
    [bugOne.sch]
2011-04-06 not finished yet ...
    [bugOne.sch]
2011-04-08 Initial PCB test ... + connectors ..
    [bugOne.sch]
2011-04-17 Add rfm12b footprint
2011-04-25 PCB starting ...
    [bugOne.sch]
2011-04-26 Added thermal points ...
    [bugOne.sch]
2011-05-01 Continuing routing ...
    [bugOne.sch]
2011-05-06 Enlarge CONN1 and CONN2
    [bugOne.sch]
2011-05-15 Move the pin header ...
2011-05-22 New power supply
    [bugOne.sch]
2011-05-22 PS fix
    [bugOne.sch]
2011-05-22 New pcb alim
2011-05-22 Changes on up big connector / power supply .. Ready for review !
2011-05-22 Change the 1206 to 0805 footprint .. 0805 are much more cheaper !!
2011-05-23 - resize connector holes - moved some silk text
2011-05-26 Design rules check + PCB home over the ISP.
2011-06-18 Add labels on connectors
2011-06-18 Change drill size of via and pin to pass DRC check
2011-07-27 Initials tests for bugOne.
    [main.c]
2011-10-11 Sample for aes usage
2011-10-11 bugone uart run at 38400bits/s
    [board.h]
2011-10-12 Move rfm12 pinout to specific board include
2011-10-12 Use timer instead of loop count to send ping
2011-11-22 Add button sample
2011-12-04 added error_cmd() and bugfix the run_cmd()
    [main.c]
2011-12-05 - Disable avrdude check for arduino. - The timer value depends on F_CPU now
2011-12-10 Fix the fuse bug
2012-01-05 Use interrupt to increment seconds count
2012-01-22 Fix support for rfm12 lib debug
    [rfm12.c]
2012-02-13 Add timeout on uart operation
2012-02-26 Get devices out of projects
2012-02-26 Use shared devices instead of private one
2012-03-01 Replace data_t structure with packet_t structure.
    [bugOne.c]
2012-03-01 Ask the right device
2012-03-17 Move main() to the framework
2012-03-18 New Makefile template (see bugone.inc and lm35/Makefile)
    [lm35.c]
2012-03-18 New sample use of makefile for dht11 project.
2012-03-21 Use the right device id..
2012-03-22 Replace hard wired bugnet
2012-03-22 Edit devices in node
2012-03-30 Replace device with node in testsuite
2012-03-30 Move devices count to init function
2012-04-03 Add a device that return a pseudo random value
2012-04-04 Change led init sequence to recognize sniffer board
2012-04-15 ds18b20 device and sample
2012-04-15 Add dht22 device and sample
2012-04-26 optiboot bootloader for bugone
    [optiboot.c, pin_defs.h]
2012-05-08 bugfix for the new makefile style
    [main.c]
2012-05-08 Added optiboot fuses support & floating point printf (change CC value to toggle)
2012-08-15 Fix init led state ..
2012-08-29 Turn On LED1 on boot
2012-09-17 More remove of DeviceData
2012-09-17 Find device for the node
2012-12-04 Add current dir in include search path
2012-12-04 Initial import of bugnet ethernet gateway
    [enc28j60.c, main.c]
2013-02-17 Import photoresistor device
2013-03-05 - Added support for sleep in rfm12 - Added support for watchdog in bugOne - Went back to bugOne applications
    [bugOne.c, main.c, rfm12.c]
2013-03-10 Added the TX_ONLY support case.
2013-03-10 Oops .. fixed the ISR too ..
    [bugOne.c]
2013-07-30 Broke the sleep example .. and decide to do new one in wdt/ dir.
    [main.c]
2013-07-30 Fix some merge issue, and switch to bugone_init like boot
    [bugOne.c, led.c, main.c]
2013-07-31 Added rfm12 sleep, and drop uart ..
2013-08-01 switch to new RFM12 power_up() power_down() API. Using this API, the bugOne draw about 35uA at sleep ..
    [main.c]
2013-08-25 Added the app .. but still buggy
    [main.c]
2013-08-25 Don't try to send packet in watchdog interrupt
2013-09-09 Add project name in firmware version print
2013-12-29 Revert "Merge branch 'master' of github.com:jkx/DIY-Wireless-Bug"
    This reverts commit 687cdaf6833b98e41a089dcf401b3868ba7d4c77, reversing
    changes made to bcd6c78a7226646490949ade666b09978d615e2f.
    [bugOne.c, enc28j60.c, led.c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]
2014-01-02 Revert "Revert "Merge branch 'master' of github.com:jkx/DIY-Wireless-Bug""
    This reverts commit 52684d4f470facb3a8ea764fa76e93ba7bea94fc.
    [bugOne.c, enc28j60.c, led.c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]
2014-01-26 power managment
2014-02-04 No power managment in bugnet gateway project
    [main.c]
2014-03-02 Split bugone_loop in bugone_send and external power managment
    [bugOne.c, ds18x20.c, main.c]
2014-03-04 Change for the led
2014-03-07 The default is now PARASITE mode for the DS18B20 because even the external power sensors works in this mode so .. x
2014-10-23 New miniaturized bugOne board
    Creating new "mini" bugOne board, with some added features:
    * MOSFET for complete poweroff of RMF12B
    * ISP moved further away from the shield
    * smaller LDO regulator (MCP1700). This might be changed in a future version
    * added a GND via near the antenna
    Next features:
    * holes to attach the board
    * jumper to short the MOSFET (in case a more usual sleep mode is desired)
    * add missing MOSFET control from the AVR
    * rotate all names
    [bugOne.sch, bugOne_mini.sch]
2014-10-24 Added MOSFET control from the AVR
    This required a brand new diod in the design, in order to avoid resetting the
    AVR when shutting down the RFM12B. Placement had to be changed.
    Minor track size modifications
    [bugOne_mini.sch]
2014-10-24 Cleaning up bugOne mini board
    * Added 3 grounded mounting holes (one is near the antenna, usable to
    ground an external antenna)
    * Removed two old capacitors, replaced by one following MCP1700 and
    XC6206 datasheets
    * Set R0 as shunt for regulator, if no regulators are soldered on the
    board.
    * Added an access to uC controlled alimentation on connector2 (V+)
    * Renamed components
    * Changed track size below the uC
    The board can still be optimized, probably by changing the AVR place (moving it
    downward). Another shunt should be provided for the MOSFET.
    [bugOne_mini.sch]
2014-10-24 Functional mini board
    Added shunt for the MOS and various modification. The only missing element is
    shield connectors label.
    [bugOne_mini.sch]
2014-10-24 Labellized and "gerberized" version of bugOne mini
2014-10-25 New pilot wire shield for bugOne mini
    This shield allows pilot wire control from bugOne. The shift register needs to
    be checked, but it allows config retention when the AVR is in standby mode with
    minimum energy consumption. The design without the shield register has been
    tested.
    Also added label on bugOne mini board
    [pilot_wire.sch]
2014-10-26 Added a new RH/T sensor shield
    This shield is designed to be used with different sensors depending on the
    requirements. It also comes with a 8P8C (RJ45) connector, connected to the same
    buses than the sensors on the board, in order to be able to put sensors further
    away from the bugOne.
    A repeater board is provided to connect the sensors with the RJ45 connectors.
    [repeater.sch, sensor_shield.sch]
2014-10-26 Adding pictures of boards for easy online browsing
2014-10-26 Added picture of routed repeater board
    This fixes the previous commit (github does not like amends...)
2014-10-27 Increasing power line on bugOne_mini board
    [bugOne_mini.sch]
2014-10-28 Rerouted pwr supply part of bugOne mini
    Cleaner routing of power supply, and configuration jumpers added :
    JMP1 to connect V+ (CONN2) to MOS controlled power line or not
    JMP2 to disconnect LDO regulator output from VCC (when using Vcc as an external regulated power line)
    [bugOne_mini.sch]
2014-10-29 Deleting HH10D from sensor board
    Sensor shield has been resized, and HH10D could not be used anymore. It has been
    deleted, and it can now be accessed through the external connector.
    A battery sense has been added (on PC2), with a Jumper to select battery input
    (Vcc or Vss).
    Minor modifications on bugOne mini main board
    [bugOne_mini.sch, sensor_shield.sch]
2014-10-29 Adding a small power supply board for 1.5V battery operation
    The board is based on a MCP1640 low power regulator. It is compatible as a power header for bugOne mini board.
    [boost_battery.sch]
2014-10-29 Adding SHT21 breakout board for repeater
    [sht21_breakout.sch]
2014-10-31 Adding boards outline
2014-10-31 Missing a jumper in bugOne mini
    [bugOne_mini.sch]
2014-10-31 Increasing clearance between mounting hole and antenna
2014-11-08 Correction of shorts on battery supply
    [boost_battery.sch]
2014-11-08 Adding picture of new supply shield
    The shield has been rerouted to correct a mistake. Ground plane was connected to
    all pins, leading to shorts.
    A new feature has also been added to be able to short the MCP1640
2014-11-22 Preliminary support for SHT21 I2C sensor
2014-11-24 Minor corrections in power shield
2014-11-24 Adding "Sleep announce" message
    This message allows proper "node presence" management in the BugNet. Before
    going in sleeping mode, the node sends a message to warn everyone that it will
    not be available. This is especially useful for nodes able to receive commands.
    Commands can be buffered until the node comes back. Receive only device should
    send a "Hello" when waking up
    [bugOne.c]
2014-11-24 Cleaning up SHT2x device
    Adding "init" function
2014-12-04 Adding a prototype Teleinfo shield
    [teleinfo.sch]
2014-12-07 Improving power management and adding bugone_mini board
    Waking up and sleeping has two modes : light and complete.
    BugOne_mini and MOSFET management are now included in bugone functions
    [board.h, bugOne.c, main.c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]
2014-12-10 Fix some typos & remove ds18b20 depends in Makefile
    [main.c]
2014-12-11 Adding longer blink in SHT21 and correcting SLEEP announce
    [bugOne.c, main.c]
2014-12-18 Fix the bandgap current leak.. tested in sht21 project.
    [bandgap.c, bugOne.c, led.c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]
2014-12-26 Changed ds18x20_init to display ROM_CODE and work with both, one or multiple devices
2014-12-29 Store ds18b20 temperature in a signed int ...
2016-10-03 Adding MOSFET management in sniffer
    Sniffer on bugone_mini did not start: the RFM12 was never started
2016-10-03 Adding bugOne helper function for send and receive loop
    The loop prepare data for all application, sends it, and wait for 250 ms for
    received data. It then loops as long as there is data to send and receive.
    [bugOne.c]
2016-10-06 Adding a case for the bugone
    This case is designed to hold a bugone with a shield, a AA (or 14500) battery,
    and has room for the up converter in case of a 1.5V AA battery (below the
    battery). It has been printed on a Ultimaker 2.
    [bugone_14500_case.fcstd, bugone_14500_lid.fcstd, bugone_case_vented.stl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]
2016-10-06 Vertical case for bugone
    These have not been tested yet
    [bugone_14500_vert_case.fcstd, bugone_14500_vert_lid.fcstd]
2016-10-11 Cleaning up the bugone stl case
    [bugone_14500_case.fcstd, bugone_14500_lid.fcstd, bugone_case_vented.stl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]
2016-10-11 Adding first try at new sensor board
    The board removes useless slots (RJ45, DHT11), and adds new sensors (SHT31D,
    BME280, BH1750). It will also have prototyping zone (2.54mm)
    [BH1750.sch, bme280.sch, sensor_shield.sch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]
2016-10-12 First placed/routed version
    Need to double check the footprints for BH1750, SHT31D and BME280
    [sensor_shield.sch]
2016-10-12 Minor modifications after DRC
    [sensor_shield.sch]
2016-10-13 Updated routing
    [sensor_shield.sch]
2016-10-13 Adding 1st pin marker on BH1750
2016-10-13 Updating PNG file for sensor_shield
2016-10-19 Adding smaller battery supply
    This one is not pin compatible with the bugOne mini, but it is smaller
    (15mmx20mm) (and with a better layout, according to the MCP1640 datasheet).
    [boost_battery.sch]
2017-03-07 Adding new KiCad based Sensor V2 shield
    [sensor_shield.kicad_pcb, sensor_shield.sch, shield.kicad_pcb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]
2017-03-07 Adding some footprints
    [sensor_shield.kicad_pcb, sensor_shield.sch]
2017-03-07 Routing of sensor shield complete
    [sensor_shield.kicad_pcb, sensor_shield.sch]
2017-03-07 Minor fixes
    [sensor_shield.kicad_pcb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]
2017-03-08 Minor fixes on sensor shield
    [sensor_shield.kicad_pcb, sensor_shield.sch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]
2017-03-08 Adding footprint for DS18B20
    [sensor_shield.sch]
2017-03-08 Templates can now be used as template on KiCad
2017-03-08 Adding ProtoShield for BugOne
    [proto_shield.kicad_pcb, proto_shield.sch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]
2017-03-09 Adding preliminary BugAQ
    [bugaq.kicad_pcb, bugaq.sch]
